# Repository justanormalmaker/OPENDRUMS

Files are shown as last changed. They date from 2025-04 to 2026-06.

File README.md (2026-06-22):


    
> The portable Open-Source sample player/drum pads based on Arduino - [Website](https://opendrums.it)

    

OPENDRUMS DEMO (https://www.youtube.com/watch?v=3pwfQyi5qWA "OPENDRUMS video demo")

Click on the image to see the video demo :)

> [!WARNING]
> You found a spoiler! The Team is working hard on a new version of OPENDRUMS... and more! Don't miss it when the time comes. Watch this repo and visit the [website](https://opendrums.vercel.app) to stay in the loop! In the meantime, the current version is fully open and ready to be hacked.

## 🚩 Table of Contents

- [About](#-about)
- [Why OPENDRUMS?](#-why-opendrums)
- [Features](#-features)
- [Hardware](#-hardware)
- [Software](#-software)
- [How to use](#%EF%B8%8F-how-to-use)

## 🚀 About

**OPENDRUMS** is an elecronic instrument similar to a **sample player or a drum pads machine** that can play any sound sample, but with the particularity of being small, portable and **Open-Source**!
When i ( [@justanormalmaker](https://github.com/justanormalmaker) ) thought of OPENDRUMS I wanted to create a relatively "simple" but at the same time cool and useful Hardware/Software project that anyone could create with a few components, a PCB, and a soldering iron. Its a good project for people that like to **create music**, like me :), and for anyone else that want to build a cool project and **learn something new**! The aim of this project is to bring music lovers closer to electronics and vice versa, leaving aside the boring theory and experimenting directly with something concrete and fun.
You can build OPENDRUMS with **55 components** and an Arduino Nano ESP32 board. You can use the instrument to play drums or any type of samples wherever and whenever you like thanks to its **9 progammable buttons** that act like pads, **rechargeable battery**, and **compact size**. For more information go to [Hardware](#-hardware)  -  [Software](#-software) - [How to use](#%EF%B8%8F-how-to-use). 

## 🥁 Why OPENDRUMS?

Because it's **Open-Source** and **Built with love**! You want to just build the 1.0v of the project, you can! You want to create your custom OPENDRUMS variation, or you want to improve OPENDRUMS and help me create the 2.0v, you can! You want to create a better code for the project, a better design, you want to add more buttons, more leds... you can! All the original code, circuit schematic and PCB desing are avilable for you, to just build OPENDRUMS 1.0, or to customaize everything! You decide!

## 🎨 Features

* **Compact size** - *100x90 mm* or *3,94x3,54 in*
* **9 progammable buttons** - *Buttons that can be programmed to play any sample*
* **OLED screen** - *For programming the button*
* **Integrated speaker**
* **2 3.5mm headphones jacks**
* **Rechargeable battery**
* **USB-C charging port** *(depends on the arduino board used)*

## 💡 Hardware

### Component list (V1.0)

* **11**  12*12mm push buttons
* **1**  ON/OFF slider switch DPDT
* **1**  push switch DPDT
* **10**  blue 5mm LEDs 
* **1**  green 5mm LED
* **1**  red 5mm LED
* **12**  1k 1/4W resistors 
* **1**  10k 1/4W resistor
* **1**  220 1/4W resistor
* **1**  50k potentiometer 
* **2**  10uf electrolytic capacitors 
* **1**  1uf ceramic capacitor
* **1**  100nf ceramic capacitor
* **1**  470uf electrolytic capacitor
* **1**  33uH SMD inductor coil
* **1**  SS24 SMD diode
* **2**  3.5mm headphones jack
* **1**  4ohm speaker
* **1**  DFPlayerMini module
* **1**  128*64 0.96" I2C OLED display
* **1**  JST 2mm connector
* **1**  AP5900 battery charger/boost converter IC (SOP-8 package)
* **1**  Arduino nano ESP32-S3

### PCB and circuit schematics

You can find everything, incluse the **schematic and the gerber file** in the repo's files. But for contest this is the **circuit schematic**:



In the schematic we found the **Arduino Nano, the buttons grid, the two buttons for programming, the volume potentiometer, LED indicators, the DFPlayermini circuit, the battery charger/boost converter circuit, and the OLED display**.

The **battery charger/boost converter circuit** is what gives stable **5V power** to the board and allow to charge a **3.7V LiPo (Lithium Polymer battery)**. The circuit is based on the **AP5900 IC**, a chinese chip used in power-banks and similar products. This specific IC requires little additional components to work **(Some capacitors, an inductor coil, a diode, and two LEDs)** and does the work of 3 ICs in 1. This circuit is connected directly to the 5V pin of the arduino through a **switch** that allows you to choose between **OFF/Charge and ON mode**:
* **ON Mode** - The board is powered by the battery.
* **OFF/Charging Mode** - The board can be powered by the arduino USB connector. If power is given (using arduino's USB connector) the battery will charge.

> [!CAUTION]
> DISCONNECT THE ARDUINO FROM ANY COMPUTER OR USB BEFORE TURNING TO ON MODE.

The **Arduino** is the brain of the board. It comunicates with all the buttons, the DFplayer, an the OLED.
* **Buttons grid** - Every button of the grid is connected to a **digital I/O (Input/output) pin** of the Arduino, setted as **INPUT**, and its also connected to **ground (GND)** and to the nagative terminal of an **LED** that is then connected to **5V**. Every LED is connected in series with a 220ohm resistor. When the button is pressed **it completes the circuit** and connects the arduino pin (pulled UP to 5V), and the negative terminal of the LED to GND. **The LED lights up and the Arduino feels the change in the state of the pin connected to the button**.
* **Buttons for programming/LED indicator** - Same thing for this buttons but this time we have only an LED connected **indipendently** to GND and to the **digital pin 13**, setted as **OUTPUT**, by the positive terminal.
* **Volume potentiometer** - It's connected to the **analog pin 3**, of the arduino and obviously to **GND and 5V**.
* **DFPlayerMini** - This module has the function of **reading and playing the audio file from an SD card**. Its connected to **GND and 5V trough a series of capacitors**, that have the function of improving the general audio quality of the module by removing the **electrical interference** caused by other components. It comunicates with arduino using the **UART (Universal Asynchronous Receiver-Transmitter) protocol** using the digital **pin 5 and pin 6**. It's also connected to a **4ohm speaker** with a slider switch (used to turn it ON and OFF) and two **3.5mm headphones jacks**.
* **OLED display** - The display comunicates with arduino using the **I2C protocol**. It comunicates using **analog pin 4 (SDA) and pin 5 (SCK)** of the arduino and it also recives **5V power**.

This all together makes up the OPENDRUMS circuit. All the connections between the various components are "enclosed" in a PCB (Printed Circuit Board) that makes the assembly of the project easy. You just have to find the necessary components and solder them in the right place! The circuit diagram and the PCB were made using a free online tool colled EasyEDA. 

### Project assembly

To assemble the project you need to have the PCB, the necessary components, and some basic soldering skills. Our PCB were produced by JLCPcb for really cheap (Like 3$ for 5 PCBs), from the Gerber file that we sent them. You can find where the components go in the circuit schematic above. 



DISCLAIMER! The PCB above is the prototipe version (v0.1) not the recent v1.0!

Soldering most of the components to the PCB was easy. The most difficult to solder were the SMD components, but with a youtube tutorial and some patience, the job was done. When soldering SMD componets you usually use an hot air station or an hot reflow plate but we easily soldered the components using a simple soldering iron. 

After soldering, we uploaded the .ino code to the Arduino, and the board was ready!

If you want to complete you project you can also 3d print [this](https://github.com/justanormalmaker/OPENDRUMS/tree/d73520e1f8d5941a42290f2c07b925489fcdf160/HARDWARE/CASE%20(Per%20prototipo%20v0.1)) case (This case is for the V0.1 but there is also a case for the V1.0 )



## 💻 Software

### Main Softwares
To function OPENDRUMS uses this [Arduino code](SOFTWARE/OPENDRUMS_V1.0_Arduino_Software.ino).
The code is divided in sections and commented so that it can be easily understood.

It also uses this [Python program](SOFTWARE/OPENDRUMS_V1.0_python_setup_software.ino).
This program has to be used on a computer to setup OPENDRUMS when in "SETUP" mode. More info in the "How to use" section below.

## ⚙️ How to Use

### Introduction
OPENDRUMS is an electronic sample player instrument that can be used like a stand-alone instrument or like a Bluetooth MIDI instrument/controller. It can play any type of sample, sound, loop... 

### Different modes and setup.
#### Mode 1: SETUP
After powering on the device (Using the power button or connecting the board to USB while off) the OLED will display the SETUP screen.
To navigate betwen YES and NO press the UP button, to enter press the PROGRAM button.
If YES is selected the device will enter in setup mode. This mode is used to tell to the board the number of sounds contained on the SD card that you can insert in the SD card slot on the side. 

> [!NOTE]
> You have to setup the board only when you add or remove files from the card.

To setup the board, connect it to a computer via USB, open the OPENDRUMS python program, insert the number of files contained in the SD and click "Send". The board will restart.

#### Mode 2: MIDI
After the SETUP screen the MIDI screen is displayed. If YES is selected the device will enter midi mode. Now it can be used like a Bluetooth midi instrument.

#### Mode 3: SD PLAY
if any of the previous mode is selected the device will enter in SD mode. Now it can be used like a stand-alone instrument that will play any sample present on the SD card inserted.

> [!IMPORTANT]
> The samples of the SD card have to be .WAW files.

### How to play.
Before playing, you have to select what sample every button will play.
To do that, press the PROGRAM button, then find the sample name (or Midi note value, in MIDI mode) you like, using the UP button, and press one of the buttons named PAD to assing the sample to that button.
To exit this "program" state press the PROGRAM button again.

> [!NOTE]
> The samples selected for the buttons will stay the same even after turning off the device until you program the buttons again.

Now to play the samples, press any of the PAD buttons and have fun!

## 📜 License

This project is licensed under the [GPLv3](https://github.com/justanormalmaker/OPENDRUMS/blob/main/LICENSE) (Software) and the [CERN-OHL-S-2.0](https://github.com/justanormalmaker/OPENDRUMS/blob/main/LICENSES/HARDWARE%20LICENSE/HARD%20LICENSE) (Hardware) © 2026 OPENDRUMS Team.

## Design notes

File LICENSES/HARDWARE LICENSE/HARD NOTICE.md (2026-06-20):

# OPENDRUMS Hardware — License Notice

Copyright (c) 2026 OPENDRUMS Project Team (Giovanni Villani, Domenico Manta)

This hardware design (schematics, PCB layouts, CAD/mechanical files, and
associated documentation) is licensed under the CERN Open Hardware Licence
Version 2 - Strongly Reciprocal (CERN-OHL-S-2.0). The full and exact text
of the license, which governs all use, copying, modification, and
Conveyance of this Covered Source, is in the HARD LICENSE file in this same
directory.

Official license steward copy, for verification:
https://ohwr.org/cern_ohl_s_v2.txt

## In plain terms

This summary is not a substitute for the HARD LICENSE file — refer to it for
the legally binding terms.

1. You may copy, modify, and Convey this hardware design, including for
   commercial purposes, and you may Make and sell physical Products based
   on it.
2. If you modify and Convey this Covered Source, or Make and Convey a
   Product based on it, you MUST license your modified Covered Source
   under this same CERN-OHL-S-2.0 license (Strongly Reciprocal).
3. You MUST retain all original copyright Notices, including a reference
   identifying this work as derived from the OPENDRUMS project, in the
   Source files and/or accompanying documentation.
4. You MUST make the Complete Source (CAD, schematics, PCB layouts, and
   all information necessary to Make the Product) publicly available to
   anyone who receives the Product or the Source.
5. No attribution on the physical product itself is required. Attribution
   is required within the Source files, design documentation, and any
   public repository or distribution channel for the design.
6. The hardware and design files are provided "AS IS", without warranty of
   any kind.

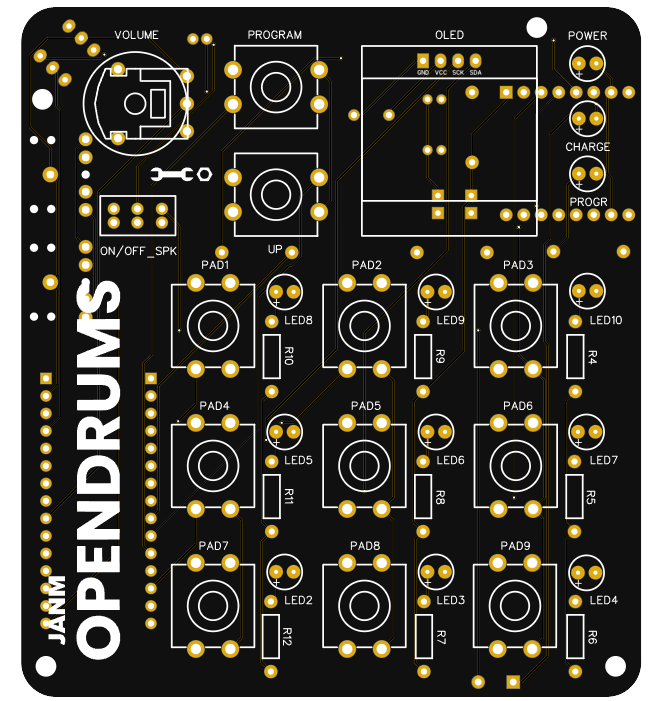
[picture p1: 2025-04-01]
RENDER/OPENDRUMS_V1.0_front.png

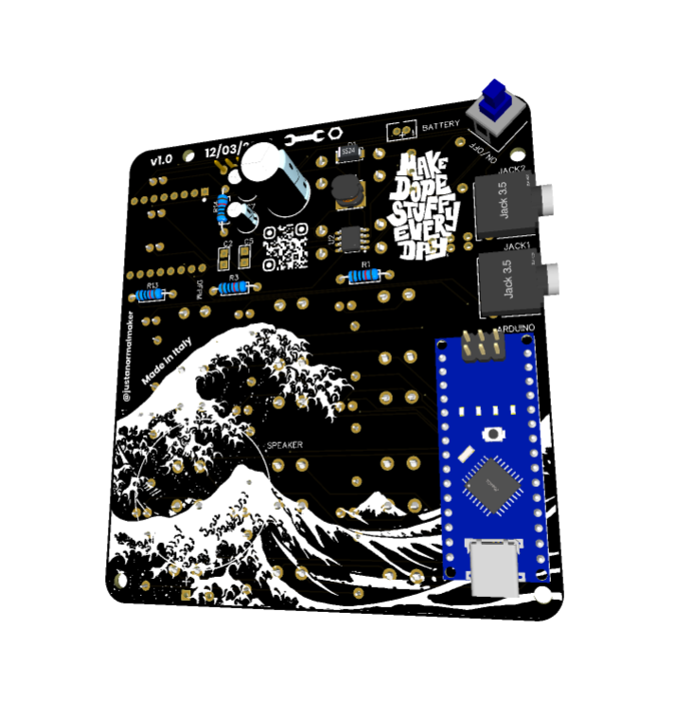
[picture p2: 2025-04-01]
RENDER/OPENDRUMS_V1.0_back_render.png

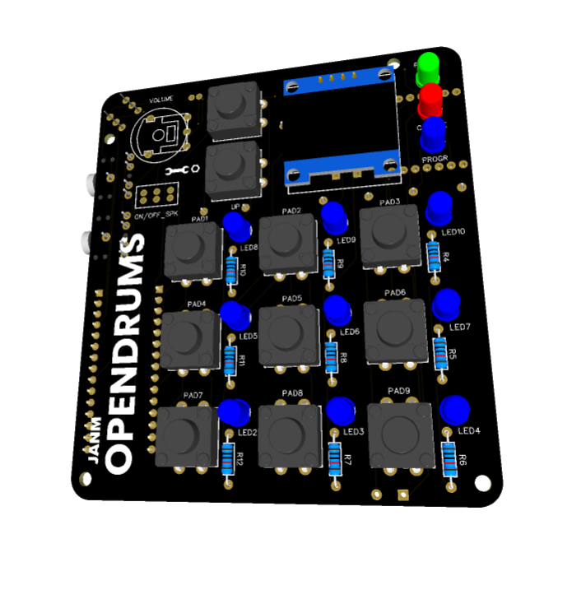
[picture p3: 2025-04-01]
RENDER/OPENDRUMS_V1.0_front_render.png

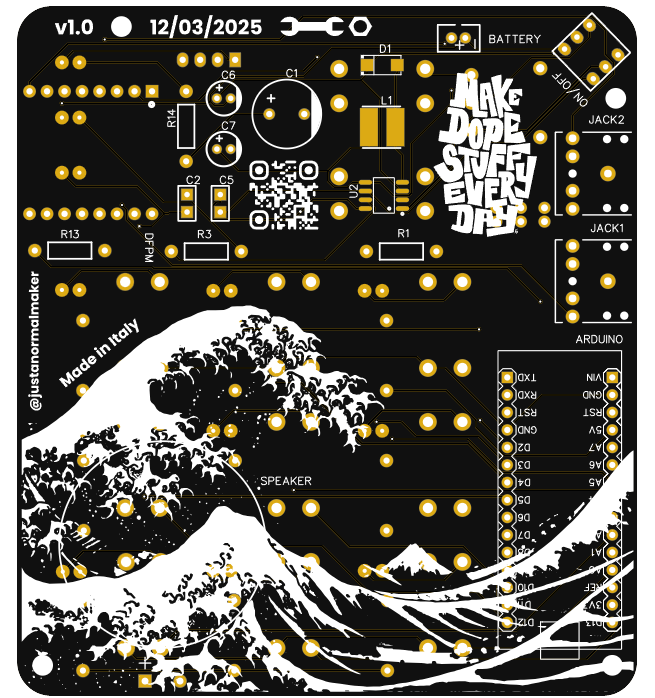
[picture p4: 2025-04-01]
RENDER/OPENDRUMS_V1.0_back.png

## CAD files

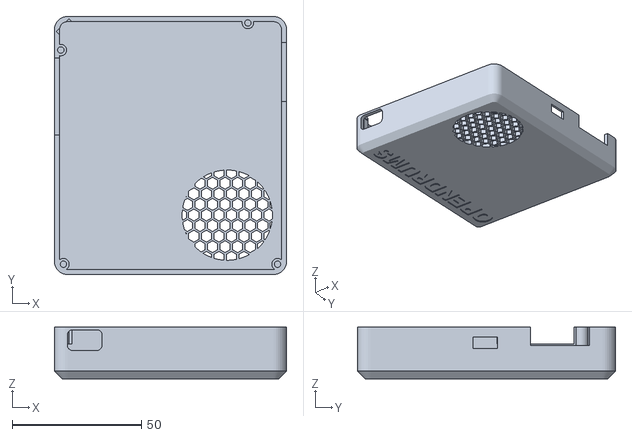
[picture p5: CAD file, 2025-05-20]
CASE/OPENDRUMS_CASE.stl
90.0 x 100.0 x 20.0

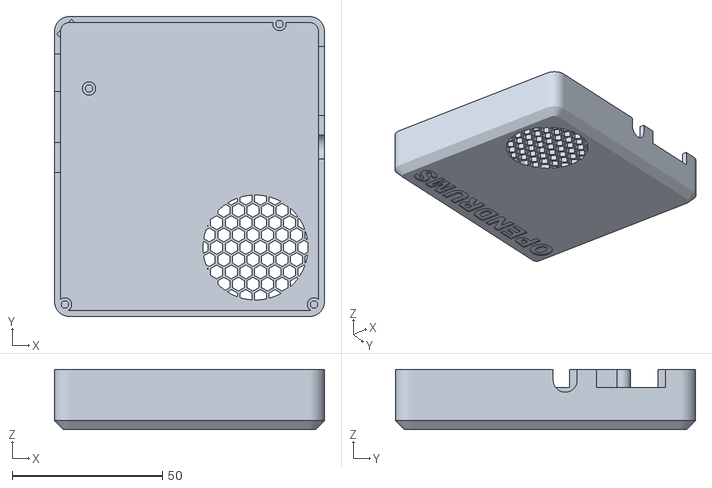
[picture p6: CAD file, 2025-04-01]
HARDWARE/CASE (Per prototipo v0.1)/OPENDRUMS_prototipe_case.stl
90.0 x 100.0 x 20.0

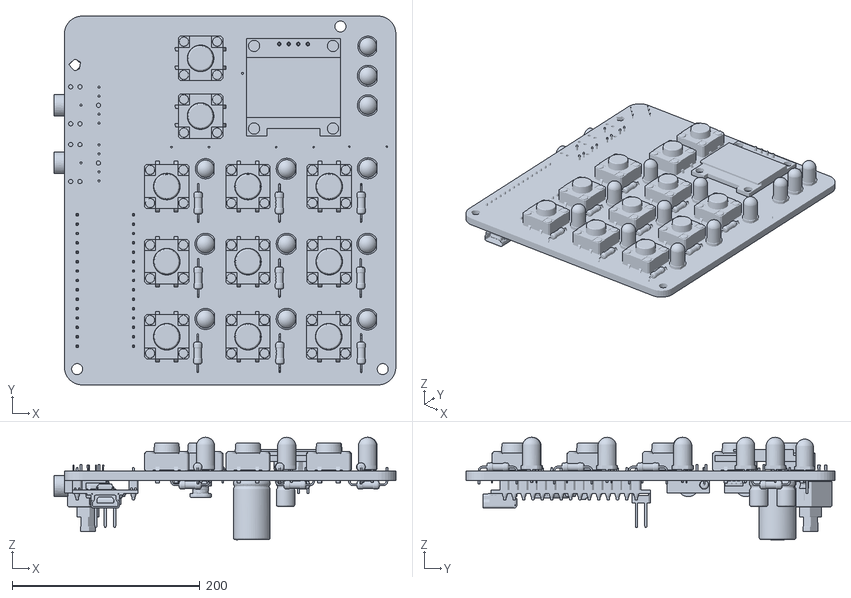
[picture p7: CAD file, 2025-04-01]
HARDWARE/OBJ_PCB_drumspad_2.obj
364.1 x 393.0 x 109.2

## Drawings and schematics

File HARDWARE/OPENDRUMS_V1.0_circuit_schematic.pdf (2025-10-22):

## TXSCK

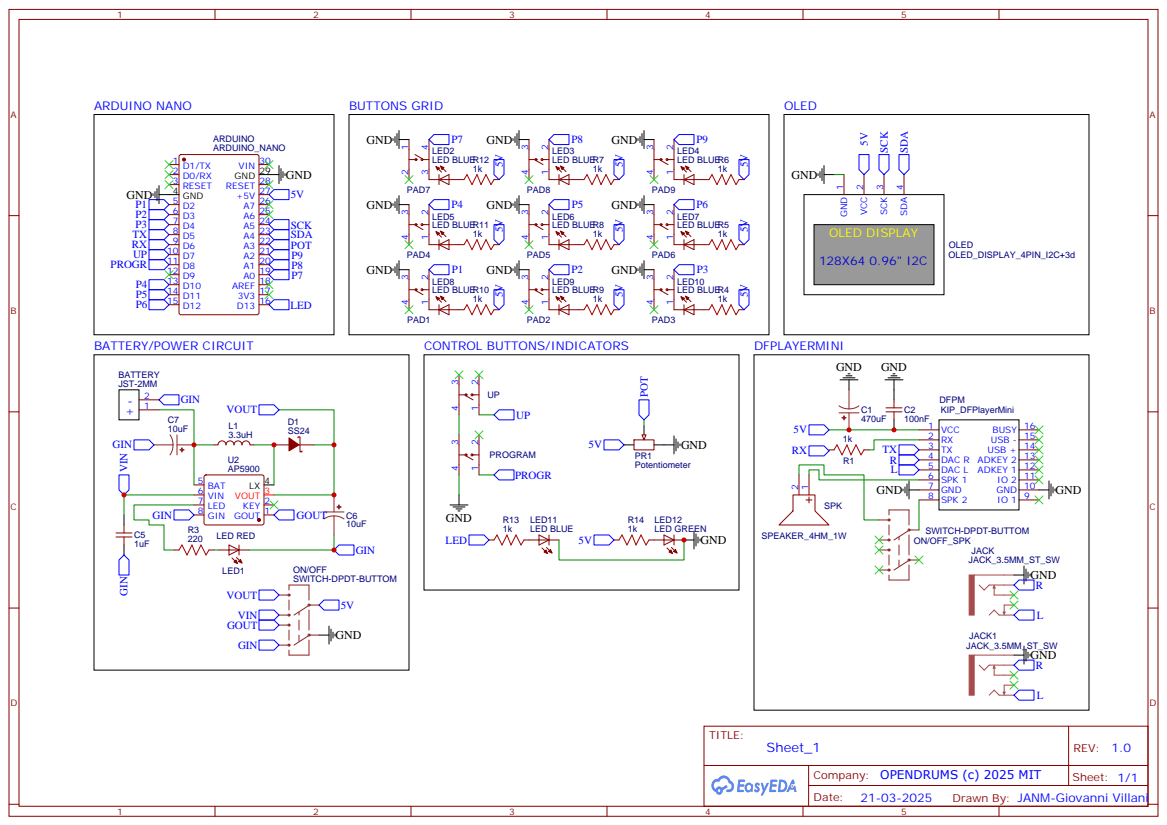
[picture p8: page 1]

Drawn By: JANM-Giovanni Villani

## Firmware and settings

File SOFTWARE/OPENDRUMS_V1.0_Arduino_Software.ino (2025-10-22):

/*
 OPENDRUMS - The Open-Source sample player
 Copyright (c) 2025 OPENDRUMS Team
 Licensed under the MIT License. See LICENSE file for details.
*/

#include <BLEMIDI_Transport.h>
#include <hardware/BLEMIDI_ESP32.h>
#include <Preferences.h>
#include <Wire.h>
#include <Adafruit_GFX.h>
#include <Adafruit_SSD1306.h>
#include <HardwareSerial.h>
#include <DFRobotDFPlayerMini.h>

/////////////////////// DICHIARAZIONE VARIABILI PAD ///////////////////////////
int PAD1 = 2;
int PAD2 = 3;
int PAD3 = 4;
int PAD4 = 10;
int PAD5 = 11;
int PAD6 = 12;
int PAD7 = A0;
int PAD8 = A1;
int PAD9 = A2;
int PROG = 8;
int UP = 7;
int POT = A3;
int SPAD1;
int SPAD2;
int SPAD3;
int SPAD4;
int SPAD5;
int SPAD6;
int SPAD7;
int SPAD8;
int SPAD9;

/////////////////////// DICHIARAZIONE VARIABILI DI LAVORO ///////////////////////////
int LED = 13;
int stato, sottostato;
int I;
int maxx;
int potValue;
int newVolValue;
int volValue;

Preferences prefs;

/////////////////////// DICHIARAZIONE OLED/DFPLAYERMINI/MIDI ///////////////////////////
#define SCREEN_WIDTH 128
#define SCREEN_HEIGHT 64
#define OLED_RESET -1  // Pin di reset, non usato con i display I2C
Adafruit_SSD1306 display(SCREEN_WIDTH, SCREEN_HEIGHT, &Wire, OLED_RESET);

HardwareSerial mySerial(1); // Pin 5 per RX, Pin 6 per TX
DFRobotDFPlayerMini myDFPlayer;

BLEMIDI_CREATE_INSTANCE("OPENDRUMS", MIDI)


///////////////////////////////////////////////////////////////////////// VOID SETUP ////////////////////////////////////////////////////////////////////////////
void setup() {
  
  /////////////////////// SETUP OLED/DFPLAYERMINI E SERIALI ///////////////////////////
  Serial.begin(115200);
  mySerial.begin(9600,SERIAL_8N1, 5, 6);

  if(!display.begin(SSD1306_SWITCHCAPVCC, 0x3C)) {
  Serial.println(F("SSD1306 allocation fallita"));
  for(;;);
  }

  if (!myDFPlayer.begin(mySerial)) {
    Serial.println("DFPlayer Mini non trovato.");
    while (true);
  }
  myDFPlayer.volume(30);

  MIDI.begin();

  prefs.begin("config", false);

  /////////////////////// SETUP VARIABILI PAD E DI LAVORO ///////////////////////////
  pinMode(PAD1, INPUT_PULLUP);
  pinMode(PAD2, INPUT_PULLUP);
  pinMode(PAD3, INPUT_PULLUP);
  pinMode(PAD4, INPUT_PULLUP);
  pinMode(PAD5, INPUT_PULLUP);
  pinMode(PAD6, INPUT_PULLUP);
  pinMode(PAD7, INPUT_PULLUP);
  pinMode(PAD8, INPUT_PULLUP);
  pinMode(PAD9, INPUT_PULLUP);
  pinMode(PROG, INPUT_PULLUP);
  pinMode(UP, INPUT_PULLUP);
  pinMode(LED, OUTPUT);

  stato = 1;  // 0 = Modalità PLAY SD, 1 = Schermata MENU', 2 = Modalità MIDI.
  sottostato = 0;
  I = 1;
  maxx = prefs.getInt("MAXX", 0);

  /////////////////////// SCHERMATA DI AVVIO ///////////////////////////
  display.clearDisplay();
  display.setTextColor(SSD1306_WHITE);
  display.setTextSize(2);  
  display.setCursor(10, 25);  
  display.print("OPENDRUMS");
  display.display();

  delay(2000);

  display.clearDisplay();
  display.display();

  /////////////////////// SCHERMATA MENU' ///////////////////////////

  while (stato == 1) {  // Controlla se la seriale è attiva

    if (digitalRead(UP) == LOW) { 
      I = I + 1;
      if (I > 2) {
        I = 1;
      }
      delay(120);
    }
    
    if (sottostato == 0){
    if (I == 1){
      display.clearDisplay();
      display.setTextColor(SSD1306_WHITE);
      display.setTextSize(2);  
      display.setCursor(5, 1);  
      display.print("SETUP?");
      display.setCursor(5, 30);  
      display.print("[YES]  NO");
      display.display();
    }

    if (I == 2){
      display.clearDisplay();
      display.setTextColor(SSD1306_WHITE);
      display.setTextSize(2);  
      display.setCursor(5, 1);  
      display.print("SETUP?");
      display.setCursor(5, 30);  
      display.print("YES  [NO]");
      display.display();
    }

    if (digitalRead(PROG) == LOW && I == 1) {

      display.clearDisplay();
      display.setTextColor(SSD1306_WHITE);
      display.setTextSize(2);  
      display.setCursor(5, 1);  
      display.print("SETUP ON!");
      display.setCursor(5, 25);  
      display.print("Go to your Computer!");
      display.display();

      while (Serial.available() == 0) {
      }

      maxx = Serial.parseInt();  // Legge un numero intero
      prefs.putInt("MAXX", maxx);

      Serial.print("Saved Number: ");
      Serial.println(maxx);

      sottostato = 1;  // 0 = Modalità PLAY
      I = 1;
    }

    if (digitalRead(PROG) == LOW && I == 2) {
      sottostato = 1;  // 0 = Modalità PLAY
      I = 1;
      delay(200);
    }
    }

    /////////////////////////////////////////////////////////////////
    
    if (sottostato == 1){
    if (I == 1){
      display.clearDisplay();
      display.setTextColor(SSD1306_WHITE);
      display.setTextSize(2);  
      display.setCursor(5, 1);  
      display.print("MIDI?");
      display.setCursor(5, 30);  
      display.print("[YES]  NO");
      display.display();
    }

    if (I == 2){
      display.clearDisplay();
      display.setTextColor(SSD1306_WHITE);
      display.setTextSize(2);  
      display.setCursor(5, 1);  
      display.print("MIDI?");
      display.setCursor(5, 30);  
      display.print("YES  [NO]");
      display.display();
    }

    if (digitalRead(PROG) == LOW && I == 1) {
      stato = 2;  // 2 = Modalità MIDI
      I = 1;

      SPAD1 = prefs.getInt("MPAD1", 0);
      SPAD2 = prefs.getInt("MPAD2", 0);
      SPAD3 = prefs.getInt("MPAD3", 0);
      SPAD4 = prefs.getInt("MPAD4", 0);
      SPAD5 = prefs.getInt("MPAD5", 0);
      SPAD6 = prefs.getInt("MPAD6", 0);
      SPAD7 = prefs.getInt("MPAD7", 0);
      SPAD8 = prefs.getInt("MPAD8", 0);
      SPAD9 = prefs.getInt("MPAD9", 0);

      delay(200);
    }

    if (digitalRead(PROG) == LOW && I == 2) {
      stato = 0;  // 0 = Modalità PLAY
      I = 1;

      SPAD1 = prefs.getInt("SPAD1", 0);
      SPAD2 = prefs.getInt("SPAD2", 0);
      SPAD3 = prefs.getInt("SPAD3", 0);
      SPAD4 = prefs.getInt("SPAD4", 0);
      SPAD5 = prefs.getInt("SPAD5", 0);
      SPAD6 = prefs.getInt("SPAD6", 0);
      SPAD7 = prefs.getInt("SPAD7", 0);
      SPAD8 = prefs.getInt("SPAD8", 0);
      SPAD9 = prefs.getInt("SPAD9", 0);

      delay(200);
    }
    }
  }
  
  if (stato == 1){
    stato = 0;
    sottostato = 1;
  }
  

  display.clearDisplay();
  display.display();
}



///////////////////////////////////////////////////////////////////////// VOID LOOP ////////////////////////////////////////////////////////////////////////////
void loop() {

  potValue = analogRead(POT);
  newVolValue = potValue / 34;

  if (newVolValue < 1) newVolValue = 1;
  if (newVolValue > 30) newVolValue = 30;

  if (newVolValue != volValue) {
  volValue = newVolValue;

  myDFPlayer.volume(volValue);
  
  }

  /////////////////////////////////////// MODALITA' SD PLAY ////////////////////////////////////////////
  
  if (stato == 0){

  /////////////////////// PROGRAMMAZIONE SUONI /////////////////////////////

  if (digitalRead(PROG) == LOW && sottostato == 0) {
    sottostato = 1;  // 1 = Modalità programma ON
    delay(200);
  }
  if (digitalRead(PROG) == LOW && sottostato == 1) {
    sottostato = 0;  // 0 = Modalità programma OFF, Modalità PLAY ON
    delay(200);
  }

  if (sottostato == 1) {
    digitalWrite(LED, HIGH);
    
    if (digitalRead(UP) == LOW) { 
      I = I + 1;
      if (I > maxx) {
        I = 1;
      }
      Serial.println(I);
      delay(120);
    }

    display.clearDisplay();  // Schermata per indicare il file che si sta scegliendo
    display.setTextSize(2);
    display.setTextColor(SSD1306_WHITE);
    display.setCursor(5, 1);
    display.print("PROGM. ON!");
    display.setCursor(5, 25);
    display.print("File ");
    display.print(I);
    display.display();

    if (digitalRead(PAD1) == LOW) {
      SPAD1 = I;
      prefs.putInt("SPAD1", SPAD1);
    }
    if (digitalRead(PAD2) == LOW) {
      SPAD2 = I;
      prefs.putInt("SPAD2", SPAD2);
    }
    if (digitalRead(PAD3) == LOW) {
      SPAD3 = I;
      prefs.putInt("SPAD3", SPAD3);
    } 
    if (digitalRead(PAD4) == LOW) {
      SPAD4 = I;
      prefs.putInt("SPAD4", SPAD4);
    }
    if (digitalRead(PAD5) == LOW) {
      SPAD5 = I;
      prefs.putInt("SPAD5", SPAD5);
    }
    if (digitalRead(PAD6) == LOW) {
      SPAD6 = I;
      prefs.putInt("SPAD6", SPAD6);
    } 
    if (digitalRead(PAD7) == LOW) {
      SPAD7 = I;
      prefs.putInt("SPAD7", SPAD7);
    }
    if (digitalRead(PAD8) == LOW) {
      SPAD8 = I;
      prefs.putInt("SPAD8", SPAD8);
    }
    if (digitalRead(PAD9) == LOW) {
      SPAD9 = I;
      prefs.putInt("SPAD9", SPAD9);
    } 
  } 
  else {
    digitalWrite(LED, LOW);
    display.clearDisplay();
    display.display();
  }
  
  
  if (digitalRead(PAD1) == LOW) {
    Serial.println(SPAD1);
    myDFPlayer.play(SPAD1);
    delay(50);
  }
  if (digitalRead(PAD2) == LOW) {
    Serial.println(SPAD2);
    myDFPlayer.play(SPAD2); 
    delay(50);
  }
   if (digitalRead(PAD3) == LOW) {
    Serial.println(SPAD3);
    myDFPlayer.play(SPAD3);
    delay(50); 
  } 
  if (digitalRead(PAD4) == LOW) {
    Serial.println(SPAD4);
    myDFPlayer.play(SPAD4);
    delay(50);
  }
  if (digitalRead(PAD5) == LOW) {
    Serial.println(SPAD5);
    myDFPlayer.play(SPAD5); 
    delay(50);
  }
   if (digitalRead(PAD6) == LOW) {
    Serial.println(SPAD6);
    myDFPlayer.play(SPAD6);
    delay(50); 
  } 
  if (digitalRead(PAD7) == LOW) {
    Serial.println(SPAD7);
    myDFPlayer.play(SPAD7);
    delay(50);
  }
  if (digitalRead(PAD8) == LOW) {
    Serial.println(SPAD8);
    myDFPlayer.play(SPAD8); 
    delay(50);
  }
   if (digitalRead(PAD9) == LOW) {
    Serial.println(SPAD9);
    myDFPlayer.play(SPAD9);
    delay(50); 
  }
  }

  /////////////////////// MODALITA' MIDI PLAY ///////////////////////////
  
  if (stato == 2){
  if (digitalRead(PROG) == LOW && sottostato == 0) {
    sottostato = 1;  // 1 = Modalità programma ON
    delay(200);
  }
  if (digitalRead(PROG) == LOW && sottostato == 1) {
    sottostato = 0;  // 0 = Modalità programma OFF, Modalità PLAY ON
    delay(200);
  }

  if (sottostato == 1) {
    digitalWrite(LED, HIGH);
    
    if (digitalRead(UP) == LOW) { 
      I = I + 1;
      if (I > 127) {
        I = 0;
      }
      Serial.println(I);
      delay(120);
    }

    display.clearDisplay();  // Schermata per indicare il valore midi che si sta scegliendo
    display.setTextSize(2);
    display.setTextColor(SSD1306_WHITE);
    display.setCursor(5, 1);
    display.print("PROGM. ON!");
    display.setCursor(5, 25);
    display.print("Midi ");
    display.print(I);
    display.display();

    if (digitalRead(PAD1) == LOW) {
      SPAD1 = I;
      prefs.putInt("MPAD1", SPAD1);
    }
    if (digitalRead(PAD2) == LOW) {
      SPAD2 = I;
      prefs.putInt("MPAD2", SPAD2);
    }
    if (digitalRead(PAD3) == LOW) {
      SPAD3 = I;
      prefs.putInt("MPAD3", SPAD3);
    } 
    if (digitalRead(PAD4) == LOW) {
      SPAD4 = I;
      prefs.putInt("MPAD4", SPAD4);
    }
    if (digitalRead(PAD5) == LOW) {
      SPAD5 = I;
      prefs.putInt("MPAD5", SPAD5);
    }
    if (digitalRead(PAD6) == LOW) {
      SPAD6 = I;
      prefs.putInt("MPAD6", SPAD6);
    } 
    if (digitalRead(PAD7) == LOW) {
      SPAD7 = I;
      prefs.putInt("MPAD7", SPAD7);
    }
    if (digitalRead(PAD8) == LOW) {
      SPAD8 = I;
      prefs.putInt("MPAD8", SPAD8);
    }
    if (digitalRead(PAD9) == LOW) {
      SPAD9 = I;
      prefs.putInt("MPAD9", SPAD9);
    } 
  } 
  else {
    digitalWrite(LED, LOW);
    display.clearDisplay();
    display.display();
  }
  
  
  if (digitalRead(PAD1) == LOW) {
    Serial.println(SPAD1);
    MIDI.sendNoteOn(SPAD1, 127, 1);
    delay(50);
  }
  if (digitalRead(PAD2) == LOW) {
    Serial.println(SPAD2);
    MIDI.sendNoteOn(SPAD2, 127, 1);
    delay(50);
  }
  if (digitalRead(PAD3) == LOW) {
    Serial.println(SPAD3);
    MIDI.sendNoteOn(SPAD3, 127, 1);
    delay(50); 
  } 
  if (digitalRead(PAD4) == LOW) {
    Serial.println(SPAD4);
    MIDI.sendNoteOn(SPAD4, 127, 1);
    delay(50);
  }
  if (digitalRead(PAD5) == LOW) {
    Serial.println(SPAD5);
    MIDI.sendNoteOn(SPAD5, 127, 1);
    delay(50);
  }
  if (digitalRead(PAD6) == LOW) {
    Serial.println(SPAD6);
    MIDI.sendNoteOn(SPAD6, 127, 1);
    delay(50); 
  } 
  if (digitalRead(PAD7) == LOW) {
    Serial.println(SPAD7);
    MIDI.sendNoteOn(SPAD7, 127, 1);
    delay(50);
  }
  if (digitalRead(PAD8) == LOW) {
    Serial.println(SPAD8);
    MIDI.sendNoteOn(SPAD8, 127, 1);
    delay(50);
  }
  if (digitalRead(PAD9) == LOW) {
    Serial.println(SPAD9);
    MIDI.sendNoteOn(SPAD9, 127, 1);
    delay(50); 
  }
  } 

  
  
}

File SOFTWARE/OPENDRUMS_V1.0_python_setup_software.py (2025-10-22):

''' 
 OPENDRUMS - The Open-Source sample player
 Copyright (c) 2025 OPENDRUMS Team
 Licensed under the MIT License. See LICENSE file for details.
'''

import serial.tools.list_ports
import time
import tkinter as tk
from tkinter import ttk

def get_serial_ports():
    ports = [port.device for port in serial.tools.list_ports.comports()]
    return ports if ports else ["No ports found"]

def send_to_arduino(port, baudrate, data):
    try:
        with serial.Serial(port, baudrate, timeout=1) as ser:
            time.sleep(2)  # Aspetta che la connessione sia stabile
            ser.write(f"{data}\n".encode())
            print(f"Send: {data}")
            result_label.config(text=f"Send {data} file at {port}", foreground="green")
    except Exception as e:
        result_label.config(text=f"Error: {e}", foreground="red")

def send_manual_count():
    try:
        file_count = int(file_count_var.get())
        arduino_port = port_var.get()
        baudrate = int(baudrate_var.get())
        send_to_arduino(arduino_port, baudrate, file_count)
    except ValueError:
        result_label.config(text="Insert a correct value.", foreground="red")

# Creazione dell'interfaccia grafica
root = tk.Tk()
root.title("OPENDRUMS Setup")
root.geometry("400x250")
root.resizable(False, False)
root.configure(bg="#f0f0f0")

file_count_var = tk.StringVar()
port_var = tk.StringVar(value="COM3")
baudrate_var = tk.StringVar(value="115200")

frame = ttk.Frame(root, padding=20)
frame.pack(fill="both", expand=True)

style = ttk.Style()
style.configure("TButton", font=("Arial", 10), padding=5)
style.configure("TLabel", font=("Arial", 10))
style.configure("TEntry", font=("Arial", 10))

# Numero di file
ttk.Label(frame, text="File number:").grid(row=0, column=0, sticky="w", pady=5)
ttk.Entry(frame, textvariable=file_count_var, width=10).grid(row=0, column=1, pady=5)

# Porta Arduino
ttk.Label(frame, text="OPENDRUMS port:").grid(row=1, column=0, sticky="w", pady=5)
ports = get_serial_ports()
port_dropdown = ttk.Combobox(frame, textvariable=port_var, values=ports, state="readonly")
port_dropdown.grid(row=1, column=1, pady=5)
if ports:
    port_var.set(ports[0])  # Imposta il primo valore disponibile

# Pulsante di invio
send_button = ttk.Button(frame, text="Send", command=send_manual_count)
send_button.grid(row=3, column=1, pady=10)

# Etichetta di stato
result_label = ttk.Label(frame, text="", font=("Arial", 10, "bold"))
result_label.grid(row=4, column=0, columnspan=2, pady=10)

root.mainloop()

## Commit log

2024-08-27 Add circuit schematic pdf
2025-03-29 Add GERBER file

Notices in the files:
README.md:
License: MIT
